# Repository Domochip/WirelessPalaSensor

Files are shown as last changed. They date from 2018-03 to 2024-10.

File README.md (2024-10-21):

# WPalaSensor

This project aims to replace the Palazzetti (Fumis) room temperature sensor by an electronic simulator.  
It allows you to push home automation temperature to the stove.  
You can then keep native modulation that reduce power automatically when desired temperature is reached.  

Fumis Controller

## Compatibility

It appears that Fumis Controller is used by those brands for their stoves : 

* Palazzetti (All)
* Jotul
* TurboFonte
* Godin
* Fonte Flamme
* Invicta

If you have this controller in your stove, it's likely to be compatible.  
Fumis Controller

## Build your adapter

All files are inside `schematic` subfolder and has been designed with KiCad (free and open source)

### Schematic

WPalaSensor schematic

### PCB

WPalaSensor PCBWPalaSensor PCB2

*We produced a small batch of this adapter for test/debugging and our personal use.
If you are interested, please PM.*

### Print your box

Box project (Fusion 360 & STL) can be found into `box` folder

WPalaSensor box

### Code/Compile/Flash

Source code can be compiled using VisualStudioCode/Platformio and flashed onto a D1 Mini  
Or  
Download latest release in Release section

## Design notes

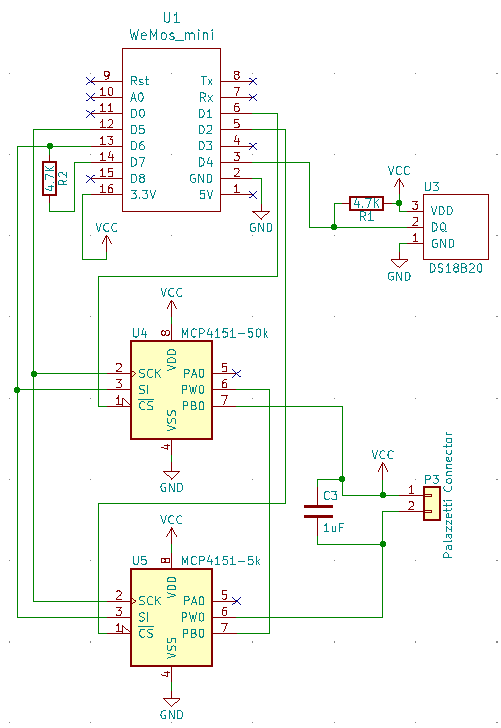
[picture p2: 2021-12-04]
img/schematic.png

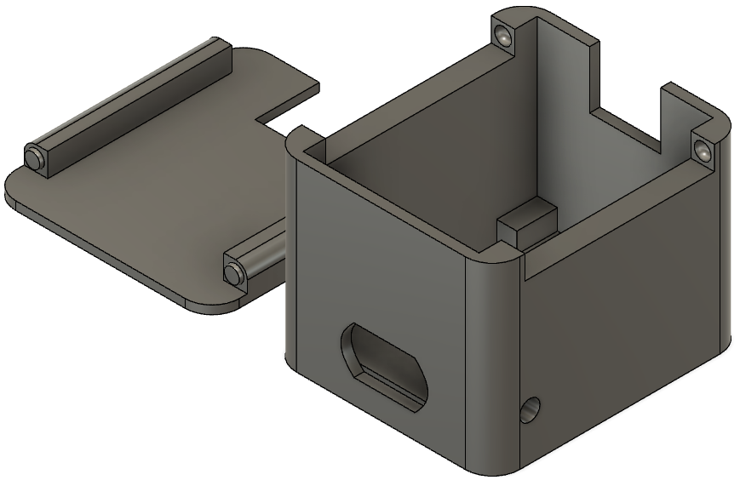
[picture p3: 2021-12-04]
img/box.png

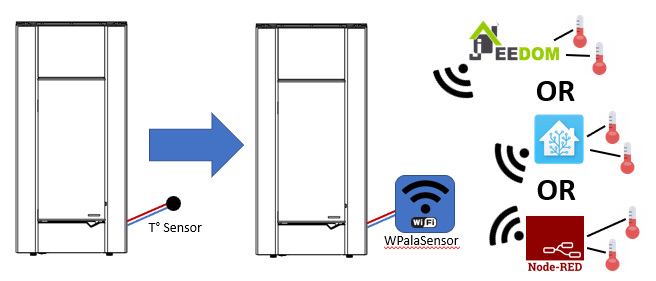
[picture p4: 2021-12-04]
img/presentation.png

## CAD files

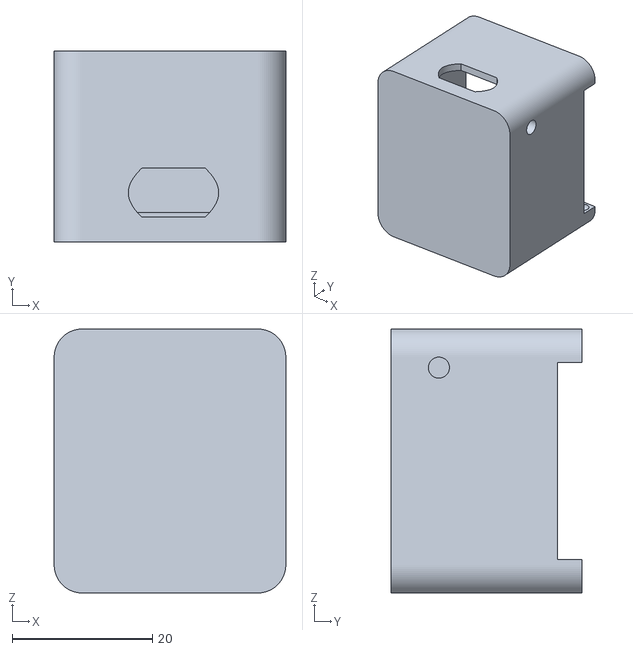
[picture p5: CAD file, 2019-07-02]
box/WirelessPalaSensor Box.stl
33.0 x 27.2 x 37.6

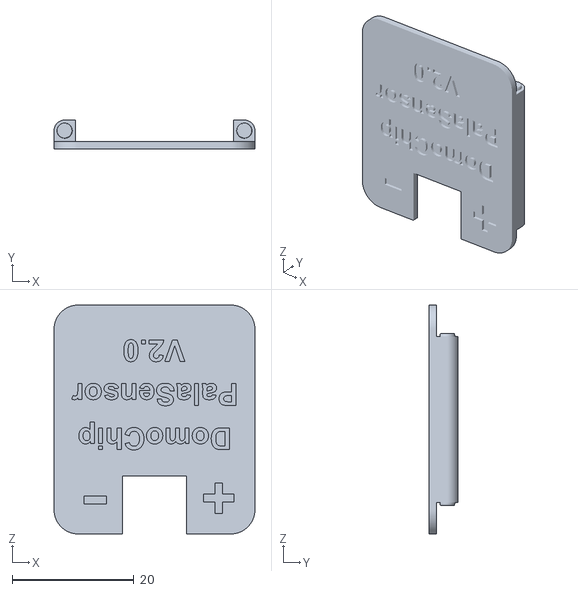
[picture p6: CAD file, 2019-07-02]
box/WirelessPalaSensor Lid.stl
33.0 x 4.75 x 37.6

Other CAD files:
box/WirelessPalaSensor v3.f3d

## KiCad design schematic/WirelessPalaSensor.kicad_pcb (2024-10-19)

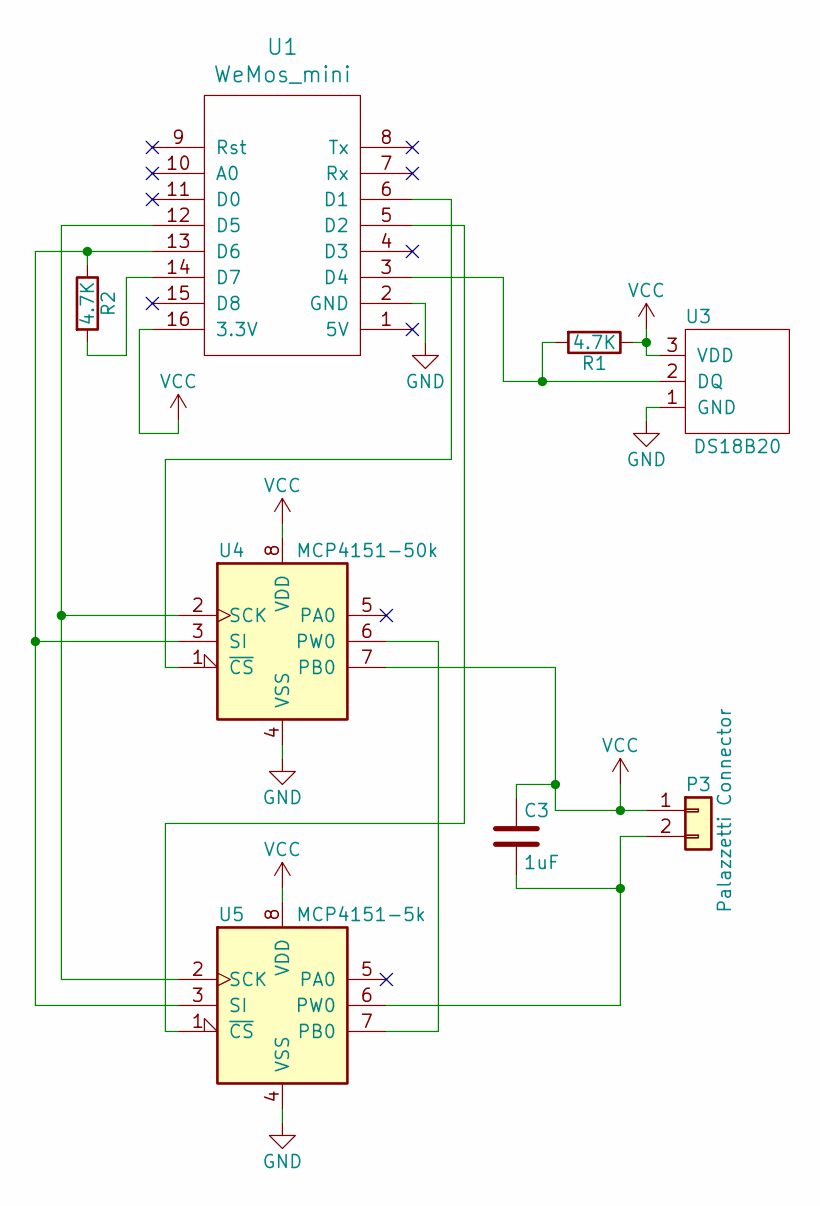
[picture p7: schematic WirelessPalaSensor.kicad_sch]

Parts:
C3: 1uF; C_0805_HandSoldering
P3: Palazzetti Connector; bornier2
R1, R2: 4.7K; R_0805_HandSoldering
U1: WeMos_mini; wemos-d1-mini-DIL-only
U3: DS18B20; Pin_Header_Straight_1x03_Pitch2.54mm
U4: MCP4151-50k; DIP-8_W7.62mm_LongPads
U5: MCP4151-5k; DIP-8_W7.62mm_LongPads

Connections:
GND: U1.2 (GND), U3.1 (GND), U4.4 (VSS), U5.4 (VSS)
unnamed: C3.2, P3.2, U5.6 (PW0)
unnamed: R1.2, U1.3 (D4), U3.2 (DQ)
unnamed: R2.1, U1.13 (D6), U4.3 (SI), U5.3 (SI)
unnamed: R2.2, U1.14 (D7)
unnamed: U1.5 (D2), U5.1 (~CS)
unnamed: U1.6 (D1), U4.1 (~CS)
unnamed: U1.12 (D5), U4.2 (SCK), U5.2 (SCK)
unnamed: U4.6 (PW0), U5.7 (PB0)
VCC: C3.1, P3.1, R1.1, U1.16 (3.3V), U3.3 (VDD), U4.7 (PB0), U4.8 (VDD), U5.8 (VDD)

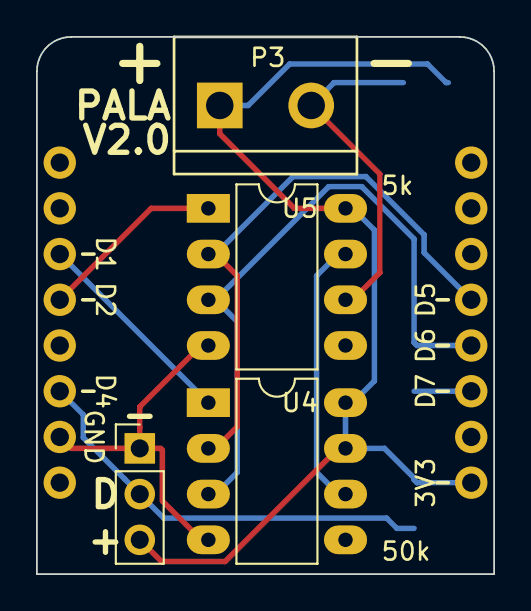
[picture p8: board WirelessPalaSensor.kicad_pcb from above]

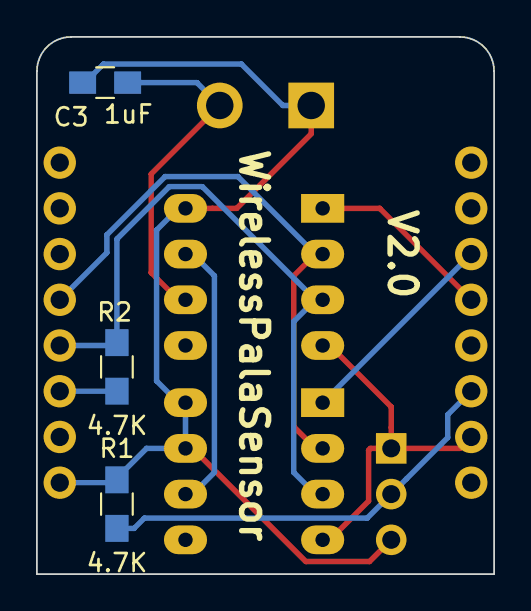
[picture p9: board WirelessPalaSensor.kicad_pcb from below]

Board: 2 copper layers, 25.4 x 29.8 mm, 8 parts (4 on the bottom side), 10 nets.

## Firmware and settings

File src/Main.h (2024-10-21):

#ifndef Main_h
#define Main_h

#include <Arduino.h>

// Helper macros to convert a define to a string
#define STRINGIFY(x) #x
#define TOSTRING(x) STRINGIFY(x)

// ----- Should be modified for your application -----
#define APPLICATION1_MANUFACTURER "Domochip"
#define APPLICATION1_MODEL "WPalaSensor"
#define APPLICATION1_CLASS WPalaSensor
#define VERSION_NUMBER "4.0.7"

#define APPLICATION1_NAME TOSTRING(APPLICATION1_CLASS)     // stringified class name
#define APPLICATION1_HEADER TOSTRING(APPLICATION1_CLASS.h) // calculated header file "{APPLICATION1_NAME}.h"
#define DEFAULT_AP_SSID APPLICATION1_NAME                  // Default Access Point SSID "{APPLICATION1_NAME}{4 digits of ChipID}"
#define DEFAULT_AP_PSK APPLICATION1_NAME "Pass"            // Default Access Point Password "{APPLICATION1_NAME}Pass"

// Control EventSourceMan code (To be used by Application if EventSource server is needed)
#define EVTSRC_ENABLED 0
#define EVTSRC_MAX_CLIENTS 2
#define EVTSRC_KEEPALIVE_ENABLED 0

#ifdef ESP8266

// Pin 12, 13 and 14 are used by DigiPot Bus
// Pins used for DigiPot Select
#define MCP4151_5k_SSPIN D2
#define MCP4151_50k_SSPIN D1
// Pin for 1Wire DS18B20 bus
#define ONEWIRE_BUS_PIN D4

#else

// Pin 19, 23 and 18 are used by DigiPot Bus
// Pins used for DigiPot Select
#define MCP4151_5k_SSPIN 21
#define MCP4151_50k_SSPIN 22
// Pin for 1Wire DS18B20 bus
#define ONEWIRE_BUS_PIN 16

#endif

// Enable developper mode (fwdev webpage and SPIFFS is used)
#define DEVELOPPER_MODE 0

// Log Serial Object
#define LOG_SERIAL Serial
// Choose Log Serial Speed
#define LOG_SERIAL_SPEED 115200

// Choose Pin used to boot in Rescue Mode
// #define RESCUE_BTN_PIN 16

// Status LED
// #define STATUS_LED_SETUP pinMode(XX, OUTPUT);pinMode(XX, OUTPUT);
// #define STATUS_LED_OFF digitalWrite(XX, HIGH);digitalWrite(XX, HIGH);
// #define STATUS_LED_ERROR digitalWrite(XX, HIGH);digitalWrite(XX, HIGH);
// #define STATUS_LED_WARNING digitalWrite(XX, HIGH);digitalWrite(XX, HIGH);
// #define STATUS_LED_GOOD digitalWrite(XX, HIGH);digitalWrite(XX, HIGH);

// construct Version text
#if DEVELOPPER_MODE
#define VERSION VERSION_NUMBER "-DEV"
#else
#define VERSION VERSION_NUMBER
#endif

#endif

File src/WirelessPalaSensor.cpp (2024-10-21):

#include "WirelessPalaSensor.h"

//-----------------------------------------------------------------------
// Steinhart–Hart reverse function
//-----------------------------------------------------------------------
void WPalaSensor::setDualDigiPot(float temperature)
{
  // convert temperature from Celsius to Kevin degrees
  float temperatureK = temperature + 273.15;

  // calculate and return resistance value based on provided temperature
  double x = (1 / _digipotsNTC.steinhartHartCoeffs[2]) * (_digipotsNTC.steinhartHartCoeffs[0] - (1 / temperatureK));
  double y = sqrt(pow(_digipotsNTC.steinhartHartCoeffs[1] / (3 * _digipotsNTC.steinhartHartCoeffs[2]), 3) + pow(x / 2, 2));
  setDualDigiPot((int)(exp(pow(y - (x / 2), 1.0F / 3) - pow(y + (x / 2), 1.0F / 3))));
}
//-----------------------------------------------------------------------
// Set Dual DigiPot resistance (serial rBW)
//-----------------------------------------------------------------------
void WPalaSensor::setDualDigiPot(int resistance)
{
  float adjustedResistance = resistance - _digipotsNTC.rWTotal - (_digipotsNTC.rBW5KStep * _digipotsNTC.dp5kOffset);

  // DigiPot positions calculation
  int digiPot50k_position = floor((adjustedResistance) / (_digipotsNTC.rBW50KStep * _digipotsNTC.dp50kStepSize)) * _digipotsNTC.dp50kStepSize;
  int digiPot5k_position = round((adjustedResistance - (digiPot50k_position * _digipotsNTC.rBW50KStep)) / _digipotsNTC.rBW5KStep);
  setDualDigiPot(digiPot50k_position, digiPot5k_position + _digipotsNTC.dp5kOffset);
}

void WPalaSensor::setDualDigiPot(unsigned int dp50kPosition, unsigned int dp5kPosition)
{
  // Set DigiPot position
  if (_mcp4151_50k.getPosition(0) != dp50kPosition)
    _mcp4151_50k.setPosition(0, dp50kPosition);
  if (_mcp4151_5k.getPosition(0) != dp5kPosition)
    _mcp4151_5k.setPosition(0, dp5kPosition);
}

//-----------------------------------------------------------------------
// Main Timer Tick (aka this should be done every 30sec)
//-----------------------------------------------------------------------
void WPalaSensor::timerTick()
{
  // LOG
  LOG_SERIAL.println(F("TimerTick"));

  // if MQTT protocol is enabled and connected then publish Core, Wifi and WPalaControl status
  if ((_ha.protocol == HA_PROTO_MQTT || _ha.cboxProtocol == CBOX_PROTO_MQTT) && _mqttMan.connected())
  {
    String baseTopic = _ha.mqtt.baseTopic;
    MQTTMan::prepareTopic(baseTopic);
    // remove the last char of baseTopic which is a '/'
    baseTopic.remove(baseTopic.length() - 1);

    JsonDocument doc;
    doc["Core"] = serialized(_applicationList[Core]->getStatusJSON());
    doc["Wifi"] = serialized(_applicationList[WifiMan]->getStatusJSON());
    doc[_appName] = serialized(getStatusJSON());

    String strJson;
    serializeJson(doc, strJson);

    _mqttMan.publish(baseTopic.c_str(), strJson.c_str(), true);
  }

  if (_skipTick)
  {
    _skipTick--;
    return;
  }

  float temperatureToDisplay = 20.0;

  // read temperature from the local sensor
  _owTemperature = _ds18b20.readTemp();
  if (_owTemperature == 12.3456F)
    _owTemperature = 20.0; // if reading of local sensor failed so push 20°C
  else
  {
    // round it to tenth
    _owTemperature *= 10;
    _owTemperature = round(_owTemperature);
    _owTemperature /= 10;
  }

  // if HomeAutomation protocol is HTTP and WiFi is connected
  if (_ha.protocol == HA_PROTO_HTTP && WiFi.isConnected())
  {

    WiFiClient client;
    WiFiClientSecure clientSecure;

    HTTPClient http;

    // set timeOut
    http.setTimeout(5000);

    // try to get HomeAutomation sensor value -----------------

    // build the complete URI
    String completeURI = String(F("http")) + (_ha.http.tls ? F("s") : F("")) + F("://") + _ha.http.hostname;
    switch (_ha.http.type)
    {
    case HA_HTTP_JEEDOM:
      completeURI = completeURI + F("/core/api/jeeApi.php?apikey=") + _ha.http.secret + F("&type=cmd&id=") + _ha.http.temperatureId;
      break;
    case HA_HTTP_FIBARO:
      completeURI = completeURI + F("/api/devices?id=") + _ha.http.temperatureId;
      break;
    case HA_HTTP_HOMEASSISTANT:
      completeURI = completeURI + F("/api/states/") + _ha.http.homeassistant.entityId;
      break;
    }

    // if not TLS then use client, else use clientSecure
    if (!_ha.http.tls)
      http.begin(client, completeURI);
    else
    {
      clientSecure.setInsecure();
      http.begin(clientSecure, completeURI);
    }

    // For Fibaro, Pass authentication if specified in configuration
    if (_ha.http.type == HA_HTTP_FIBARO && _ha.http.fibaro.username[0])
      http.setAuthorization(_ha.http.fibaro.username, _ha.http.secret);

    // For HomeAssistant, Pass long-lived access token and set content type
    if (_ha.http.type == HA_HTTP_HOMEASSISTANT)
    {
      http.addHeader(F("Authorization"), String(F("Bearer ")) + _ha.http.secret);
      http.addHeader(F("Content-Type"), F("application/json"));
    }

    // send request
    _haRequestResult = http.GET();

    if (_haRequestResult == 200)
    {
      WiFiClient *stream = http.getStreamPtr();

      char payload[60] = {0};
      int nb = 0;

      switch (_ha.http.type)
      {
      case HA_HTTP_JEEDOM:

        nb = stream->readBytes(payload, 5);
        payload[nb] = 0;
        break;

      case HA_HTTP_FIBARO:

        while (http.connected() && stream->find("\"value\""))
        {
          // go to first next double quote (or return false if a comma appears first)
          if (stream->findUntil("\"", ","))
          {
            // read value (read until next doublequote)
            nb = stream->readBytesUntil('"', payload, sizeof(payload) - 1);
            payload[nb] = 0;
          }
        }
        break;

      case HA_HTTP_HOMEASSISTANT:

        while (http.connected() && stream->find("\"state\""))
        {
          // go to first next double quote (or return false if a comma appears first)
          if (stream->findUntil("\"", ","))
          {
            // read value (read until next doublequote)
            nb = stream->readBytesUntil('"', payload, sizeof(payload) - 1);
            payload[nb] = 0;
          }
        }
        break;
      }

      // if we readed some bytes
      if (nb)
      {
        // convert to float
        float haTemperature = atof(payload);
        String strHATemperature(payload);
        strHATemperature.replace("0", "");

        // if we got a correct value
        if (haTemperature != 0.0F || strHATemperature == ".")
        {
          // round it to tenth
          haTemperature *= 10;
          haTemperature = round(haTemperature);
          haTemperature /= 10;

          // place it in global _haTemperature and store millis
          _haTemperature = haTemperature;
          _haTemperatureMillis = millis();
        }
      }
    }
    http.end();
  }

  // if ConnectionBox protocol is HTTP and WiFi is connected
  if (_ha.cboxProtocol == CBOX_PROTO_HTTP && WiFi.isConnected())
  {
    WiFiClient client;

    HTTPClient http;
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

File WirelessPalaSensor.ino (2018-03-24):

#include "WirelessPalaSensor.h"

//-----------------------------------------------------------------------
// Steinhart–Hart reverse function
//-----------------------------------------------------------------------
void WebPalaSensor::SetDualDigiPot(float temperature)
{
  //convert temperature from Celsius to Kevin degrees
  float temperatureK = temperature + 273.15;

  //calculate and return resistance value based on provided temperature
  double x = (1 / digipotsNTC.steinhartHartCoeffs[2]) * (digipotsNTC.steinhartHartCoeffs[0] - (1 / temperatureK));
  double y = sqrt(pow(digipotsNTC.steinhartHartCoeffs[1] / (3 * digipotsNTC.steinhartHartCoeffs[2]), 3) + pow(x / 2, 2));
  SetDualDigiPot((int)(exp(pow(y - (x / 2), 1.0F / 3) - pow(y + (x / 2), 1.0F / 3))));
}
//-----------------------------------------------------------------------
// Set Dual DigiPot resistance (serial rBW)
//-----------------------------------------------------------------------
void WebPalaSensor::SetDualDigiPot(int resistance)
{
  float adjustedResistance = resistance - digipotsNTC.rWTotal - (digipotsNTC.rBW5KStep * digipotsNTC.dp5kOffset);

  //DigiPot positions calculation
  int digiPot50k_position = floor((adjustedResistance) / (digipotsNTC.rBW50KStep * digipotsNTC.dp50kStepSize)) * digipotsNTC.dp50kStepSize;
  int digiPot5k_position = round((adjustedResistance - (digiPot50k_position * digipotsNTC.rBW50KStep)) / digipotsNTC.rBW5KStep);
  SetDualDigiPot(digiPot50k_position, digiPot5k_position + digipotsNTC.dp5kOffset);
}

void WebPalaSensor::SetDualDigiPot(int dp50kPosition, int dp5kPosition)
{
  //Set DigiPot position
  if (_mcp4151_50k.getPosition(0) != dp50kPosition)
    _mcp4151_50k.setPosition(0, dp50kPosition);
  if (_mcp4151_5k.getPosition(0) != dp5kPosition)
    _mcp4151_5k.setPosition(0, dp5kPosition);
}

//-----------------------------------------------------------------------
// Main Timer Tick (aka this should be done every 30sec)
//-----------------------------------------------------------------------
void WebPalaSensor::TimerTick()
{
  if (_skipTick)
  {
    _skipTick--;
    return;
  }

  float temperatureToDisplay = 20.0;
  float previousTemperatureToDisplay;
  if (_homeAutomationTemperatureUsed)
    previousTemperatureToDisplay = _homeAutomationTemperature;
  else
    previousTemperatureToDisplay = _owTemperature;
  _stoveTemperature = 0.0;
  _homeAutomationTemperature = 0.0;
  _homeAutomationTemperatureUsed = false;

  //LOG
  Serial.println(F("TimerTick"));

  //read temperature from the local sensor
  _owTemperature = _ds18b20.ReadTemp();
  if (_owTemperature == 12.3456F)
    _owTemperature = 20.0; //if reading of local sensor failed so push 20°C
  else
  {
    //round it to tenth
    _owTemperature *= 10;
    _owTemperature = round(_owTemperature);
    _owTemperature /= 10;
  }

  char payload[60];
  WiFiClient *stream;

  //if ConnectionBox option enabled in config
  if (connectionBox.enabled)
  {
    HTTPClient http1;

    //try to get current stove temperature info ----------------------
    http1.begin(String(F("http://")) + IPAddress(connectionBox.ip).toString() + F("/sendmsg.php?cmd=GET%20TMPS"));
    //set timeOut
    http1.setTimeout(5000);
    //send request
    _stoveRequestResult = http1.GET();
    //if we get successfull HTTP answer
    if (_stoveRequestResult == 200)
    {

      stream = http1.getStreamPtr();

      //if we found TMP_ROOM_WATER in answer
      if (stream->find("\"TMP_ROOM_WATER\""))
      {
        //read until the comma into payload variable
        int nb = stream->readBytesUntil(',', payload, sizeof(payload) - 1);
        payload[nb] = 0; //end payload char[]
        //if we read some bytes
        if (nb)
        {
          //look for start position of TMP_ROOM_WATER value
          byte posTRW = 0;
          while ((payload[posTRW] == ' ' || payload[posTRW] == ':' || payload[posTRW] == '\t') && posTRW < nb)
            posTRW++;

          _stoveTemperature = atof(payload + posTRW); //convert
        }
        payload[0] = 0;
      }
    }
    http1.end();
  }

  //if Jeedom option enabled in config
  if (ha.enabled == 1)
  {
    HTTPClient http2;

    //try to get house automation sensor value -----------------
    String completeURI = String(F("http")) + (ha.tls ? F("s") : F("")) + F("://") + ha.hostname + F("/core/api/jeeApi.php?apikey=") + ha.jeedom.apiKey + F("&type=cmd&id=") + ha.temperatureId;
    if (!ha.tls)
      http2.begin(completeURI);
    else
    {
      char fpStr[41];
      http2.begin(completeURI, Utils::FingerPrintA2S(fpStr, ha.fingerPrint));
    }
    //set timeOut
    http2.setTimeout(5000);
    //send request
    _homeAutomationRequestResult = http2.GET();
    //if we get successfull HTTP answer
    if (_homeAutomationRequestResult == 200)
    {

      stream = http2.getStreamPtr();

      //get the answer line
      int nb = stream->readBytes(payload, (http2.getSize() > sizeof(payload) - 1) ? sizeof(payload) - 1 : http2.getSize());
      payload[nb] = 0;

      if (nb)
      {

        //convert
        _homeAutomationTemperature = atof(payload);
        //round it to tenth
        _homeAutomationTemperature *= 10;
        _homeAutomationTemperature = round(_homeAutomationTemperature);
        _homeAutomationTemperature /= 10;
      }
      payload[0] = 0;
    }
    http2.end();
  }

  //if Fibaro option enabled in config
  if (ha.enabled == 2)
  {
    HTTPClient http3;

    //try to get house automation sensor value -----------------
    String completeURI = String(F("http")) + (ha.tls ? F("s") : F("")) + F("://") + ha.hostname + F("/api/devices?id=") + ha.temperatureId;
    //String completeURI = String(F("http")) + (ha.tls ? F("s") : F("")) + F("://") + ha.hostname + F("/devices.json");
    if (!ha.tls)
      http3.begin(completeURI);
    else
    {
      char fpStr[41];
      http3.begin(completeURI, Utils::FingerPrintA2S(fpStr, ha.fingerPrint));
    }

    //Pass authentication if specified in configuration
    if (ha.fibaro.username[0])
      http3.setAuthorization(ha.fibaro.username, ha.fibaro.password);

    //set timeOut
    http3.setTimeout(5000);
    //send request
    _homeAutomationRequestResult = http3.GET();

    //if we get successfull HTTP answer
    if (_homeAutomationRequestResult == 200)
    {

      stream = http3.getStreamPtr();

      while (http3.connected() && stream->find("\"value\""))
      {
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

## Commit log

2018-03-13 V3.2.2 Initial Commit
    [WirelessPalaSensor v1.2.scad, WirelessPalaSensor.kicad_pcb, WirelessPalaSensor.sch]
2018-05-22 Switch to PlatformIO
    [WirelessPalaSensor BOM v1.1.xlsx]
2018-06-20 Switch to Base V1.0.10
2018-11-17 Switch to Base V1.1.6
    - No More PowerShell
    - GZIP and convertion to header done in python with platformIO
    - Webpages small improvement
2019-03-17 V3.2.3 Upgrade to Base V1.1.7
    [WirelessPalaSensor.sch]
2019-03-30 V3.2.4 Update to base V1.2.1
    [WirelessPalaSensor BOM v1.1.xlsx]
2019-04-02 Fix timing and Ticker init
    [Main.h, WirelessPalaSensor.cpp]
2019-04-07 Fix calibration web page
2019-06-01 Update Schematic to D1 Mini
    [WirelessPalaSensor.kicad_pcb, WirelessPalaSensor.sch]
2019-07-02 V3.3.0 Switch to D1 Mini
2019-07-02 New Box for D1 Mini based model
    [WirelessPalaSensor Box.stl, WirelessPalaSensor Lid.stl, WirelessPalaSensor v1.2.scad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]
2020-11-01 Increase query failure count
    [WirelessPalaSensor.cpp]
2020-12-31 Add refresh period and Max Failed Request in conf
    [Main.h, WirelessPalaSensor.cpp, WirelessPalaSensor.h]
2021-12-04 Update schematic
    [WirelessPalaSensor.sch]
2023-12-17 WirelessBase update
2023-12-17 Replace AsyncWebServer by ESP8266WebServer
    [WirelessPalaSensor.cpp, WirelessPalaSensor.h]
2024-05-08 Fix build on !Windows
    [Main.h, WirelessPalaSensor.h]
2024-05-14 Adapt code for ArduinoJson7
2024-09-26 Make McpDigitalPot ESP32 compatible
2024-09-26 Adapt Pins to ESP32 MiniKit
2024-09-26 Add ESP32 MiniKit to platformio.ini
2024-09-26 Adapt Ticker for ESP32
2024-09-28 Switch to JSON POST and reuse parseConfigJSON
2024-09-28 calibration page save button should send json too
2024-09-28 Calibration actions switch to json post
2024-09-28 V4.0.1 Base update + post switched to Json
2024-09-29 Remove tls fingerprint
2024-09-29 Remove fingerPrint
2024-09-29 Fix bad cboxIp in savefile
    [WirelessPalaSensor.cpp]
2024-09-29 V4.0.2 Fix + Home Assistant MQTT autodiscovery
    [Main.h]
2024-10-06 Implement TemperatureTimeout variables
2024-10-06 Fix incorrect config ids
    [WirelessPalaSensor.cpp]
2024-10-06 Avoid Delta calculation at the first Tick call
    [WirelessPalaSensor.cpp, WirelessPalaSensor.h]
2024-10-17 Move Calibration to Config webpage (#3)
    * Add calibration div inside config.html
    * Add inputs used for calibration
    * Add getSteinhartHart function to config.html
    * Add eventListeners for calibration buttons
    * remove calib.html
    * Improve calibButton eventListener code
2024-10-19 Update schematic to KiCAD8
    [WirelessPalaSensor.kicad_pcb, WirelessPalaSensor.kicad_sch, WirelessPalaSensor.sch]
2024-10-19 Add KiCad gitignore
2024-10-21 Rename files from WirelessPalaSensor to WPalaSensor
